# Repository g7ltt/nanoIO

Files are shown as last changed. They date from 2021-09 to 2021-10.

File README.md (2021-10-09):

# nanoIO
nanoIO CW/RTTY keyer for Arduino Nano

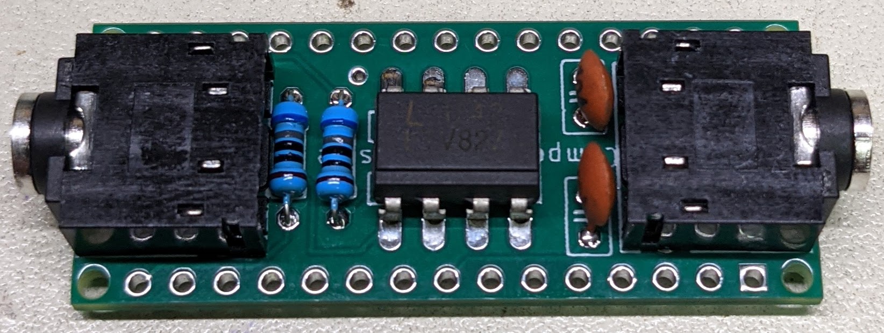
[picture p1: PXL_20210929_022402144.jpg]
finished board


My take on W1HKJ's nanoIO CW/RTTY keyer for FLDigi.

https://oshpark.com/shared_projects/0wyCgFsd

Mount the board component side down on the bottom of the Arduino Nano.

**_From the nanoIO website_**
NanoIO Version 1.3.1 
Authors: David Freese, W1HKJ & Ervin Hegedüs, HA2OS

An FSK / CW interface based on the Arduino nano. Sketch includes an FSK modulator, a CW computer interface, and a CW iambic-A/B keyer.

**FSK Specifications** 
* 5 bit Baudot
* Baud rates 45.45, 50, 75 and 100

**CW Specifications**
* 5 to 100 WPM
* dash/dot ratio adjustable 2.5 to 3.5
* in-line increment decrement WPM using ^ and | characters
* incremental size user adjustable
* PTT signal generated by Arduino

**Both**
* An internal buffer of 200 characters is available for buffered transmit.

**Hardware requirement**
* Arduino nano or compatible
* LTV-827 dual opto-isolator
* 2 620 ohm ¼ watt resistor (should work with 500 < R < 820 ohm)
* 2 0.1uF capacitor
* Suitable connectors to interface to transceiver

More information here http://www.w1hkj.com/files/nanoIO/

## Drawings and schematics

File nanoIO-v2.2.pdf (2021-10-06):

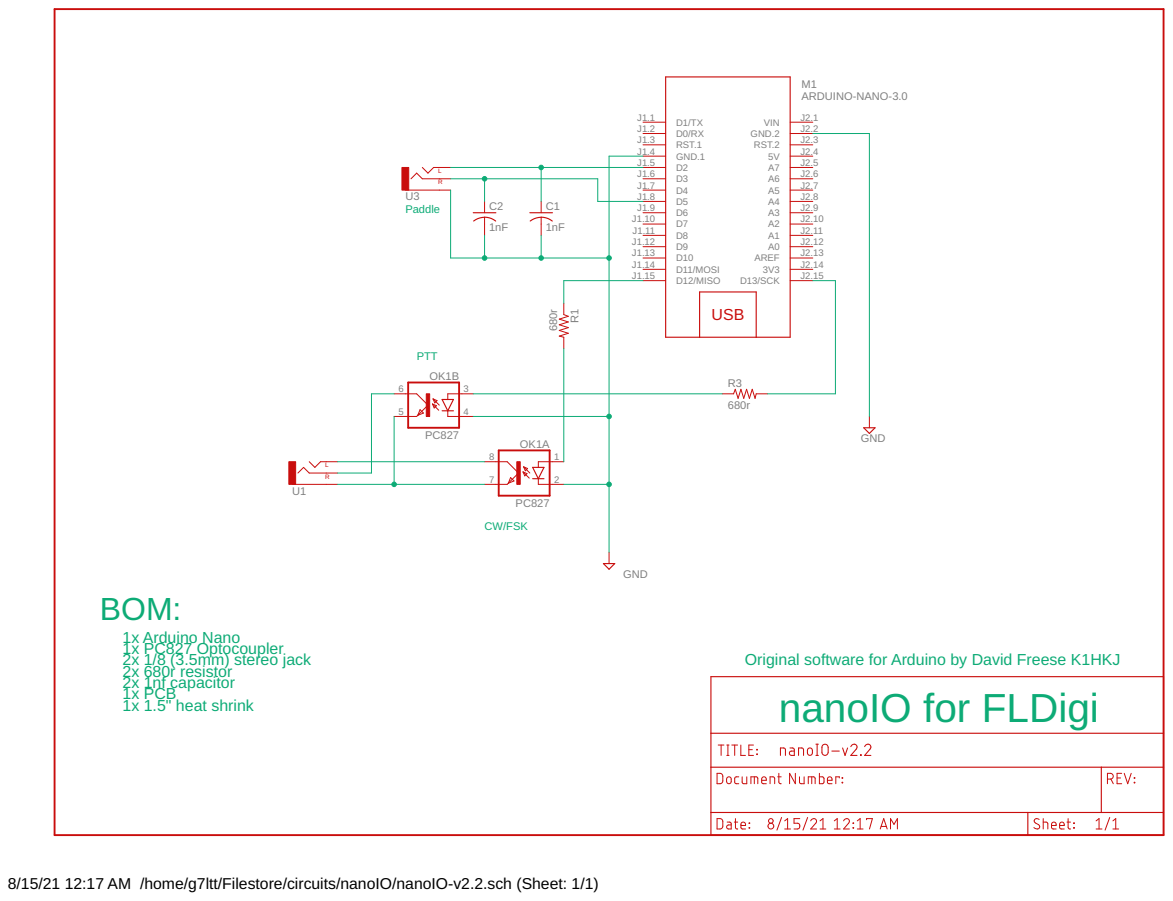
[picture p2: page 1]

Original software for Arduino by David Freese K1HKJ
nanoIO for FLDigi

8/15/21 12:17 AM /home/g7ltt/Filestore/circuits/nanoIO/nanoIO-v2.2.sch (Sheet: 1/1)

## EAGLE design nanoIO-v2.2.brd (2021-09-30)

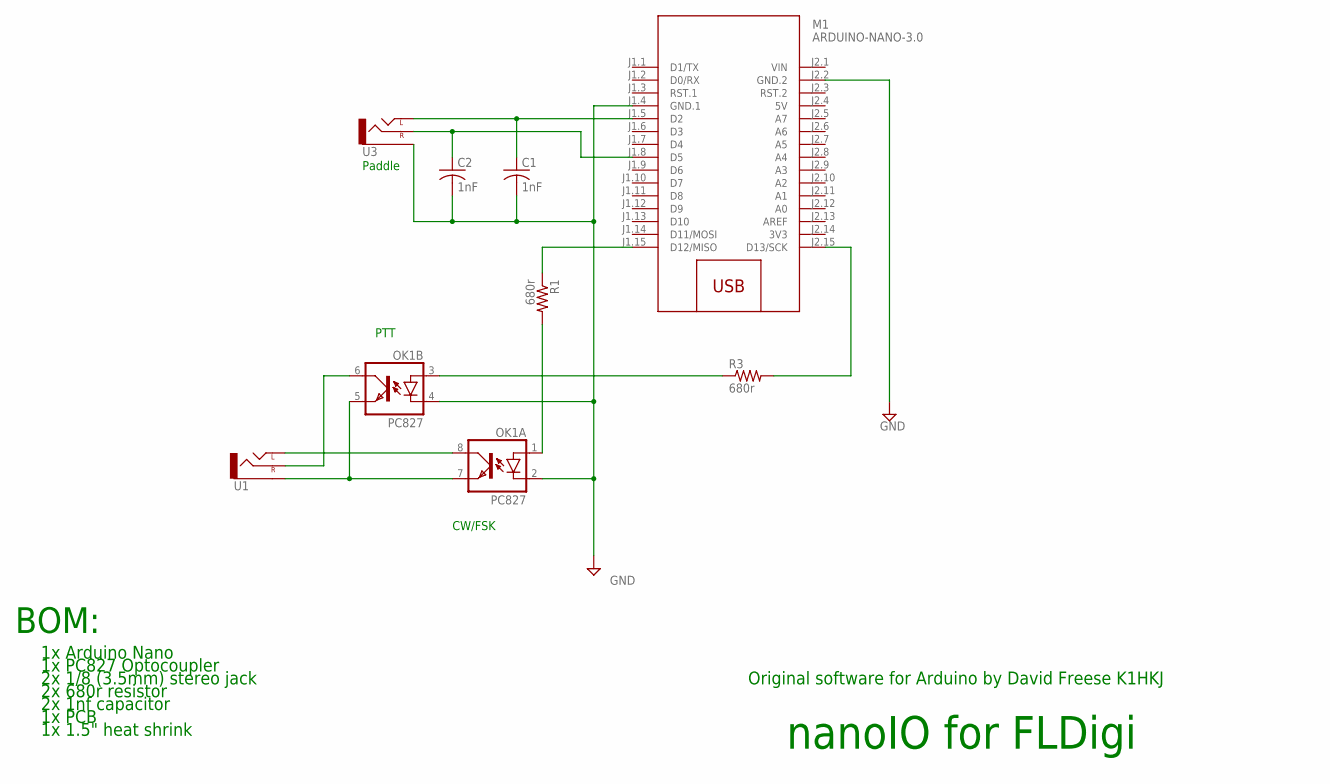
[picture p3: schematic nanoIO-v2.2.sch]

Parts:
C1, C2: 1nF; C025-025X050
M1: ARDUINO-NANO-3.0
OK1: PC827; DIL08
R1, R3: 680r; 0204/7
U1, U3: AUDIO-JACKPTH; AUDIO-JACK

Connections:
3V3: M1.J2.14 (3V3)
5V: M1.J2.4 (5V)
GND: C1.2, C2.2, M1.J1.4 (GND.1), M1.J2.2 (GND.2), OK1.2 (C), OK1.4 (C), U3.SLEEVE
unnamed: C1.1, M1.J1.5 (D2), U3.TIP (LEFT)
unnamed: OK1.1 (A), R1.2
unnamed: C2.1, M1.J1.8 (D5), U3.RING (RIGHT)
unnamed: M1.J2.15 (D13/SCK), R3.2
unnamed: M1.J1.15 (D12/MISO), R1.1
unnamed: OK1.5 (EMIT), OK1.7 (EMIT), U1.SLEEVE
unnamed: OK1.8 (COL), U1.TIP (LEFT)
unnamed: OK1.3 (A), R3.1
unnamed: OK1.6 (COL), U1.RING (RIGHT)
VIN: M1.J2.1 (VIN)

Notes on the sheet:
nanoIO for FLDigi
CW/FSK
Paddle
PTT
Original software for Arduino by David Freese K1HKJ
BOM:
1x Arduino Nano
1x PC827 Optocoupler
2x 1/8 (3.5mm) stereo jack
2x 680r resistor
2x 1nf capacitor
1x PCB
1x 1.5" heat shrink

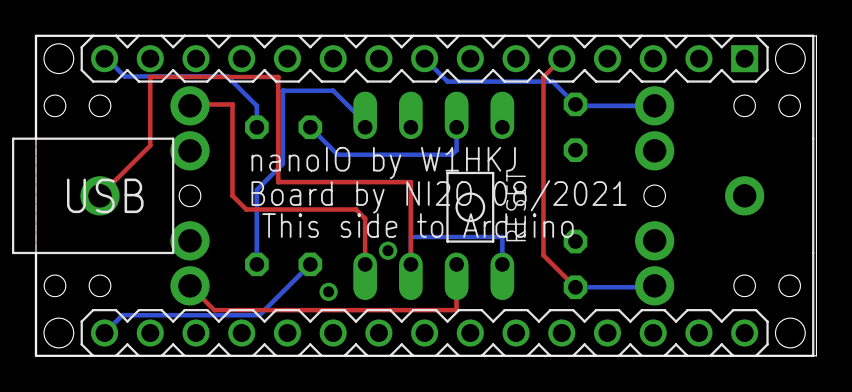
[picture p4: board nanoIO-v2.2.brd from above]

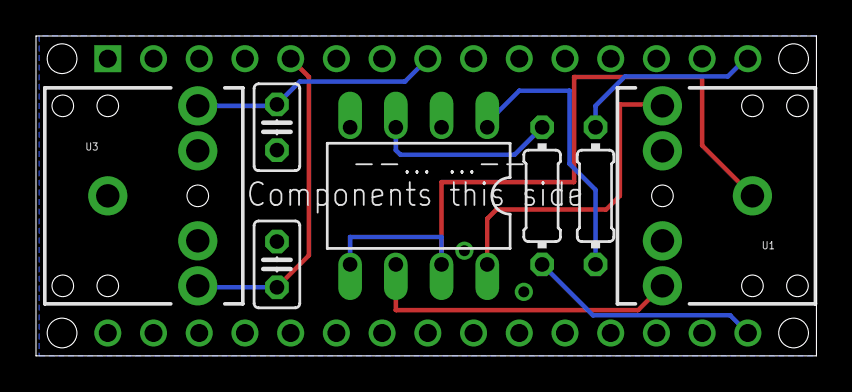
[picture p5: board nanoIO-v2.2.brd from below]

Board: 2 copper layers, 43.4 x 17.8 mm, 8 parts (7 on the bottom side), 10 nets.

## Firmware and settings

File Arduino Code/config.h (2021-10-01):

/***********************************************************************

  nanoIO

  CW / FSK interface sketch for use either stand alone or with fldigi.

  It is designed to fit within the RAM and I/O constraints of an Arduino 
  Nano circuit board.  It generates either CW 5 to 100 WPM Morse code, 
  or FSK Baudot hardline signals of 45.45, 50 or 75 Baud.

  Copyright (C) 2018 David Freese W1HKJ
  Derived from tinyFSK by Andrew T. Flowers K0SM

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
  Revisions:

  //1.0.0:  Initial release
  //1.0.1:  MORTTY Version 3 board support
  //1.1.0:  added support for WPM potentiometer; wiper on A0
  //1.3.0:  added additional FSK echo of control strings
  //1.3.1:  enabled keyline inputs
  //1.4.0:  MORTTY Version 4 board support
  //1.4.1:  Modified usec corr usage
  //1.4.1-NI2O Added NI2O board

***********************************************************************/
#ifndef _CONFIG_H_
#define _CONFIG_H_

#define VERSION "1.4.1"

// Configure for target h/w by removing the comment on the appropriate line
// ONLY one of the following:

//#define MORTTY_V2
//#define MORTTY_V3
//#define MORTTY_V4
//#define HA2OS
//#define W1HKJ
//#define N1MM
#define NI2O

// Configure for target h/w by removing the comment if your Morrty has a 
// speed pot:

//#define WITH_SPEED_POT

//----------------------------------------------------------------------
// values which may need to be changed depending on specific hardware
//----------------------------------------------------------------------

//----------------------------------------------------------------------
//Arduino pins for FSK, CW and PTT to control transmitter
// uncomment the desired h/w configuration
// comment the others

#ifdef MORTTY_V2
//----------------------------------------------------------------------
// Configuration for MORTTY Version 2 circuit board
//----------------------------------------------------------------------
#  define FSK_PIN 11
#  define CW_PIN  11
#  define PTT_PIN 13
#  define ST_Pin 4      // Sidetone Output Pin on Pin 4
// paddle input pins compatible with MORTTY board
#  define LP_in 2       // Left Paddle Input on Pin 2
#  define RP_in 5       // Right Paddle Input on Pin 5
#  define DEFAULT_MODE CW_MODE
#endif

#ifdef MORTTY_V3
//----------------------------------------------------------------------
// Configuration for MORTTY Version 3 circuit board
//----------------------------------------------------------------------
#  define FSK_PIN 11
#  define CW_PIN  12
#  define PTT_PIN 13
#  define ST_Pin 4      // Sidetone Output Pin on Pin 4
// paddle input pins compatible with MORTTY board
#  define RP_in 2       // Right Paddle Input on Pin 2
#  define LP_in 5       // Left Paddle Input on Pin 5
#  define DEFAULT_MODE CW_MODE
#  define WPM_POT 0
#endif

#ifdef MORTTY_V4
//----------------------------------------------------------------------
// Configuration for MORTTY Version 4 circuit board
//----------------------------------------------------------------------
#  define FSK_PIN 12
#  define CW_PIN  11
#  define PTT_PIN 13
#  define ST_Pin 4      // Sidetone Output Pin on Pin 4
// paddle input pins compatible with MORTTY board
#  define RP_in 2       // Right Paddle Input on Pin 2
#  define LP_in 5       // Left Paddle Input on Pin 5
#  define DEFAULT_MODE CW_MODE
#  define WPM_POT 0
#endif

#ifdef HA2OS
//----------------------------------------------------------------------
// Configuration for HA2OS quad opto-isolator circuit board design
//----------------------------------------------------------------------
#    define FSK_PIN 12
#    define CW_PIN  10
#    define PTT_PIN 11
#    define ST_Pin 4      // Sidetone Output Pin on Pin 4
//   paddle input pins
#    define LP_in 5       // Left Paddle Input on Pin 2
#    define RP_in 2       // Right Paddle Input on Pin 5
#    define DEFAULT_MODE CW_MODE
#endif

#ifdef W1HKJ
//----------------------------------------------------------------------
// Configuration for W1HKJ quad opto-isolator circuit board design
//----------------------------------------------------------------------
#    define FSK_PIN 12
#    define CW_PIN  11
#    define PTT_PIN 10
#    define ST_Pin 4      // Sidetone Output Pin on Pin 4
//   paddle input pins
#    define LP_in 2       // Left Paddle Input on Pin 2
#    define RP_in 5       // Right Paddle Input on Pin 5
#    define DEFAULT_MODE CW_MODE
#endif

#ifdef NI2O
//----------------------------------------------------------------------
// Configuration for NI2O dual opto-isolator circuit board design
//----------------------------------------------------------------------
#    define FSK_PIN 12
#    define CW_PIN  12
#    define PTT_PIN 13
#    define ST_Pin 4      // Sidetone Output Pin on Pin 4
//   paddle input pins
#    define LP_in 2       // Left Paddle Input on Pin 2
#    define RP_in 5       // Right Paddle Input on Pin 5
#    define DEFAULT_MODE CW_MODE
#endif

#endif // __CONFIG_H_

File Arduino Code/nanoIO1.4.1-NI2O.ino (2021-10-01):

/***********************************************************************

  nanoIO

  CW / FSK interface sketch for use either stand alone or with fldigi.

  It is designed to fit within the RAM and I/O constraints of an Arduino 
  Nano circuit board.  It generates either CW 5 to 100 WPM Morse code, 
  or FSK Baudot hardline signals of 45.45, 50 or 75 Baud.

  Copyright (C) 2018 David Freese W1HKJ
  Derived from tinyFSK by Andrew T. Flowers K0SM

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
  Revisions:

 //1.0.0:  Initial release
 //1.0.1:  MORTTY Version 3 board support
 //1.1.0:  added support for WPM potentiometer; wiper on A0
 //1.3.0:  added additional FSK echo of control strings
 //1.3.1:  enabled keyline inputs
 //1.4.0:  MORTTY Version 4 board support
 //1.4.1:  Modified usec corr usage
 //1.4.1-NI2O : Added NI2O board


***********************************************************************/

#include "TimerOne.h"
#include "Morse.h"
#include "Keyer.h"

#include "EEPROM.h"
#include "constants.h"
#include "ascii_map.h"

#include "config.h"

/******************************************************
     Variable declarations
*******************************************************/

/*******************************************************
  This section defines static runtime variables that affect
  RTTY transmission.  They are NOT directly changeable by user
  commands because they can get ops into trouble.  They are
  here for the tinkerer/experimenter in case you want access
  to them at runtime.
********************************************************/

long serialSpeed = 9600; //This is the speed for the serial
//(more likely USB) connection, 8-N-1

// Not user selectable, but USOS behavior can be changed here.
// We set this to TX extra shifts to be compatible with silly
// MMTTY default reciever
int usos = USOS_MMTTY_HACK;

int stopBits =  STOP_BITS_1R5;  // TX 1.5 stop bits

/***************************************
  Dynamic runtime variables these are minipulated with
  user commands or during normal TX operation.
*****************************************/
float baudrate = 45.45;  //default--can be changed by user command

int pttLeadMillis = 150; //time before first start bit
int pttTailMillis = 25;  //time after last stop bit


// Polarity--changed with user commands and stored in EEPROM
boolean mark = LOW;     //High indicates +V on the FSK/CW pin
boolean space = HIGH;   //Low indicates 0V on the FSK/CW pin

// Buffer management variables to handle TX text input
byte sendBufferArray[SEND_BUFFER_SIZE];  // size of TX buffer
byte sendBufferBytes = 0;    // number of bytes unsent in TX buffer
byte lastAsciiByteSent = 0;  // needed to echo back sent characters to terminal
boolean endWhenBufferEmpty = true;  //flag to kill TX when buffer empty (']')


byte currentShiftState = SHIFT_UNKNOWN;  //Keeps track of Letter/Figs state to determine
//if we need to send shift chars

boolean ptt = false; // Keeps track of PTT state (true = Transmitter is on)

volatile boolean isrFlag = false;   //set by timer interrupt.  Set high every 1/2 bit
//to indicate when we should exectute the bit-banging
//routine.  This is handled in the main loop function.

boolean configurationMode = false;  //flag indicates if we are in the menu system or
//in normal operation.

char mode = DEFAULT_MODE;
//----------------------------------------------------------------------
// CW variables

CWSTRUC CWstruc {
  18,      // int   cw_wpm;
  300,     // int   weight;
  2,       // int   incr;
  18,      // int   key_wpm;
  0,       // int   corr_usec
  IAMBICA, // int   keyer_mode;
  1,       // int   ptt_enable;
  10,      // int   pot min value;
  20       // int   pot range value;
};

boolean pot_control = true;
int     spd_cmd = 18;
float   wt_cmd = 3.0;

int     value = 0;
boolean value_string = false;
boolean pot_string = false;
boolean ptt_string = false;
boolean incr_char = false;

Morse morse(CWstruc.cw_wpm, CWstruc.weight/100.0);
Keyer keyer(CWstruc.key_wpm, CWstruc.weight/100.0);

//----------------------------------------------------------------------

/*********************************************************************
  Main execution
***********************************************************************/

/**
  Exectutes *once* at program start (when power applied or
  reset button pressed.  Note that many Arudino devices have a
  "software reset" option that will reset the processor when
  the serial port is opened.
  It opens the port, configures the output pins, and loads
  configuration from EEPROM.
*/

void setup()
{
// configure pins for output
  pinMode(FSK_PIN, OUTPUT);
  pinMode(PTT_PIN, OUTPUT);
  pinMode(CW_PIN, OUTPUT);

  eeLoad();

  morse.wpm(CWstruc.cw_wpm);
  morse.weight(CWstruc.weight/100.0);
  keyer.wpm(CWstruc.key_wpm);
  keyer.set_mode(CWstruc.keyer_mode);

  Serial.begin(serialSpeed);

// start the half-bit timer.
  initTimer();

//  resetSendBuffer();
  sendBufferBytes = 0;

//  morse.send('E', CW_PIN);

// Tell N1MM we are in "RX" mode.
  Serial.write("\ncmd:\n");

  morse.send('T', CW_PIN);
}

/**
  Main loop.  This loop does two things:
  (1) Process any input from the serial connection one byte at a time.

  (2) If the half-bit timer interrupt fired we need to execute the bit-banging
  routine to keep clocking out RTTY.
*/

void do_serial()
{
// Read up to SEND_BUFFER_SIZE characters from the USB serial port

  while ((Serial.available() > 0) && (sendBufferBytes < SEND_BUFFER_SIZE)) {

// get incoming byte:
    byte b = Serial.read();

// Process configuration string if we are in configuration mode
    if (configurationMode) {
      echo(b);
      handleConfigurationCommand(b);
    }
    else  switch (b) {
// test for configuration mode character
      case COMMAND_ESCAPE :
        configurationMode = true;
        echo(b);
        break;
// check for TX abort character.  This immediately kills the
// transmitter and dumps anything remaining in the buffer.
      case TX_ABORT : 
        echo(b);
        setPTT(false);
        resetSendBuffer();
        endWhenBufferEmpty = true;
        break;
      case TX_ON : 
        echo(b);
        endWhenBufferEmpty = false;
        setPTT(true);
        break;
      case TX_END : 
        echo(b);
        endWhenBufferEmpty = true;
        break;
      default :
// add character (b) to send buffer
        if (b == 0) break;
        if (mode == FSK_MODE)
          addToSendBuffer(b);
        else {
          if (b < ' ') {
            addToSendBuffer(' ');
          } else {
            addToSendBuffer(b);
          }
        }
      }
  }  // end while (Serial.available...)

// If the ISR fired we need may need to bit-bang something out the FSK port
  if (mode == FSK_MODE) {
    if (isrFlag) {
      processHalfBit();
      isrFlag = false;
    } else
      isrFlag = false;
  }
  else { // mode is CW_MODE
    if (sendBufferBytes > 0) {
      send_next_CW_char();
    } else if (endWhenBufferEmpty) {
      setPTT(false);
      endWhenBufferEmpty = false;
    }
  }
}

void send_wpm()
{
  Serial.write("\nwpm "); Serial.println(CWstruc.key_wpm);
}


void send_ptt_state()
{
  Serial.write("ptt ");
  if (CWstruc.ptt_enable) Serial.write(" enabled\n");
  else Serial.write(" disabled");
}
  
// Read A0, wiper arm of speed pot, 0 ... 5 v
// convert to wpm MIN ... MAX

void read_pot_wpm()  
{
#ifdef WITH_SPEED_POT
  int pot_wpm = CWstruc.min_pot_wpm + CWstruc.rng_pot_wpm * analogRead(WPM_POT) / 1023;

  if ((pot_control == 1) && (pot_wpm != CWstruc.cw_wpm)) {
    CWstruc.key_wpm = pot_wpm;
    keyer.wpm(CWstruc.key_wpm);
  }
#endif
}

void loop()
{
  if (mode == CW_MODE) {
    read_pot_wpm();
    if (!keyer.do_paddles()) 
      do_serial();
  } else
    do_serial(); 
}

// Handle configuration change commands by changing variables
// and writing new values to EEPROM.
//
// Configuration change commands are preceded by the ~ character
//
// ~A, ~a - IambicA keying
// ~B, ~b - IambicB keying
// ~K, ~k - Straight Key
// ~C, ~c - change to CW output
// ~E, ~e - timing error corr in usec
// ~F, ~f - change to FSK output
// ~P1    - CW WPM Pot control ON
// ~P0    - CW WPM Pot control OFF
// ~P?    - CW WPM reading
// ~X0    - disable PTT
// ~X1    - enable PTT
// ~X?    - PTT state
// ~T, ~t - enable CW tune position (] terminates)
// ~Snnns - change CW WPM to nnn
// ~Unnnu - change CW keyer WPM to nnn
// ~Dnnnd - change CW dash/dot ratio to nnn/100
// ~In    - change CW incr/decr value (1...9)
// ~0     - Set FSK mark = HIGH
// ~1     - Set FSK mark = LOW
// ~4     - Set FSK baud to 45.45
// ~5     - Set FSK baud to 50.0
// ~7     - Set FSK baud to 75.0
// ~9     - Set FSK baud to 100.0
// ~?     - Report current configuration
// ~W     - Save config to EEPROM
// ~~     - Show command set

void handleConfigurationCommand(byte b)
{
  if (value_string && b >= '0' && b <= '9') {
    value = value * 10 + b - '0';
    return;
  }
  if (pot_string) {
    if (b == '1') pot_control = 1;
    else if (b == '0') pot_control = 0;
    else if (b == '?') send_wpm();
    pot_string = false;
    configurationMode = false;
    return;
  }
  if (ptt_string) {
    if (b == '1') CWstruc.ptt_enable = 1;
    else if (b == '0') CWstruc.ptt_enable = 0;
    else if (b == '?') send_ptt_state(); 
    ptt_string = false;
    configurationMode = false;
    return;
  }
  if (incr_char) {
    int val = b - '0';
    if (val > 0 && val < 10) CWstruc.incr = val;
    incr_char = false;
  }

  switch (b) {
    case 'A' : case 'a' :
        CWstruc.keyer_mode = IAMBICA;
        keyer.set_mode(IAMBICA);
        configurationMode = false;
        break;
    case 'B' : case 'b' :
        CWstruc.keyer_mode = IAMBICB;
        keyer.set_mode(IAMBICB);
        configurationMode = false;
        break;
    case 'K' : case 'k':
        CWstruc.keyer_mode = STRAIGHT;
        keyer.set_mode(STRAIGHT);
        configurationMode = false;
        break;
    case 'C' : case 'c' :
        mode = CW_MODE;
        configurationMode = false;
        break;
    case 'F' : case 'f' :
        mode = FSK_MODE;
        configurationMode = false;
        break;
    case 'P' : case 'p' :
        pot_string = true;
        break;
    case 'X': case 'x' :
        ptt_string = true;
        break;
    case 'T' : case 't' :
        enable_tune();
        configurationMode = false;
        break;
    case COMMAND_POLARITY_MARK_HIGH :
        mark = HIGH;
        space = LOW;
        EEPROM.write(EE_POLARITY_ADDR, b);
        configurationMode = false;
        break;
    case COMMAND_POLARITY_MARK_LOW :
        mark = LOW;
        space = HIGH;
        EEPROM.write(EE_POLARITY_ADDR, b);
        configurationMode = false;
        break;
    case COMMAND_45BAUD :
        baudrate = 45.45;
        initTimer();
        EEPROM.write(EE_SPEED_ADDR, b);
        configurationMode = false;
        break;
    case COMMAND_50BAUD :
        baudrate = 50.0;
        initTimer();
        EEPROM.write(EE_SPEED_ADDR, b);
        configurationMode = false;
        break;
    case COMMAND_75BAUD :
        baudrate = 75.0;
        initTimer();
        EEPROM.write(EE_SPEED_ADDR, b);
        configurationMode = false;
        break;
    case COMMAND_100BAUD :
        baudrate = 100.0;
        initTimer();
        EEPROM.write(EE_SPEED_ADDR, b);
        configurationMode = false;
        break;
    case 'D' : // start dash/dot ratio
        value_string = true;
        value = 0;
        return;
    case 'd' : // end dash/dot ratio
        value_string = false;
        if (value >= 250 && value <= 350) {
          CWstruc.weight = value;
          morse.weight(CWstruc.weight/100.0);
        }
        configurationMode = false;
        break;
    case 'E' : // start timing error usec
        value_string = true;
        value = 0;
        return;
    case 'e' : // end dash/dot ratio
        value_string = false;
        CWstruc.corr_usec = value;
        configurationMode = false;
        break;
    case 'I' : case 'i' : // incr/dec value
        incr_char = true;
        return;
    case 'S' : // start Speed (wpm)
        value_string = true;
        value = 0;
        return;
    case 's' : // end speed
        value_string = false;
        if (value >= MIN_CW_WPM && value <= MAX_CW_WPM) {
          CWstruc.cw_wpm = value;
          morse.wpm(CWstruc.cw_wpm);
        }
        configurationMode = false;
        break;
    case 'U' : // start key wpm (user)
        value_string = true;
        value = 0;
        return;
    case 'u' : // end speed
        value_string = false;
        if (value >= MIN_CW_WPM && value <= MAX_CW_WPM) {
          CWstruc.key_wpm = value;
          keyer.wpm(CWstruc.key_wpm);
        }
        configurationMode = false;
        break;

    case 'M' : // start pot min wpm 
        value_string = true;
        value = 0;
        return;
    case 'm' : // end pot min wpm
        value_string = false;
        CWstruc.min_pot_wpm = value;
        configurationMode = false;
        break;

    case 'N' : // start pot range wpm 
        value_string = true;
        value = 0;
        return;
    case 'n' : // end pot min wpm
        value_string = false;
        CWstruc.rng_pot_wpm = value;
        configurationMode = false;
        break;

    case COMMAND_DUMP_CONFIG :
        displayConfiguration();
        configurationMode = false;
        break;
    case 'W' : case 'w' :
      eeSave();
      configurationMode = false;
      break;
    case COMMAND_ESCAPE :
      displayConfigurationPrompt();
      configurationMode = false;
      break;
    default :
      value_string = false;
      configurationMode = false;
      pot_string = false;
      ptt_string = false;
      Serial.write("\nCommand?\n");
  }
}

/**
  Loads speed and polarity from EEPROM
*/
void eeLoad()
{
  mode           = EEPROM.read(EE_MODE);
  if (mode != CW_MODE && mode != FSK_MODE) mode = CW_MODE;
  byte speedChar = EEPROM.read(EE_SPEED_ADDR);
  byte polarity  = EEPROM.read(EE_POLARITY_ADDR);

  if (polarity == COMMAND_POLARITY_MARK_LOW) {
    mark = LOW;
  } else {
    mark = HIGH;
  }
  space = !mark;

  switch (speedChar) {
    case COMMAND_50BAUD :
        baudrate = 50.0;
        break;
    case COMMAND_75BAUD :
        baudrate = 75.0;
        break;
    case COMMAND_100BAUD :
        baudrate = 100.0;
        break;
    default:
        baudrate = 45.45;
        break;
  }

  EEPROM.get(EE_CW_STRUC_ADDR, CWstruc);
  if (CWstruc.cw_wpm < MIN_CW_WPM) CWstruc.cw_wpm = 18;
  if (CWstruc.cw_wpm > MAX_CW_WPM) CWstruc.cw_wpm = 18;
  if (CWstruc.key_wpm < MIN_CW_WPM) CWstruc.key_wpm = 18;
  if (CWstruc.key_wpm > MAX_CW_WPM) CWstruc.key_wpm = 18;
  if (CWstruc.weight < 250) CWstruc.weight = 300;
  if (CWstruc.weight > 350) CWstruc.weight = 300;
  if (CWstruc.ptt_enable < 0 || CWstruc.ptt_enable > 1) CWstruc.ptt_enable = 1;
  if (CWstruc.min_pot_wpm < 5 || CWstruc.min_pot_wpm > 100) CWstruc.min_pot_wpm = 5;
  if (CWstruc.rng_pot_wpm < 10 || CWstruc.rng_pot_wpm > 30) CWstruc.rng_pot_wpm = 20;
  if (CWstruc.incr < 1) CWstruc.incr = 2;
  if (CWstruc.incr > 9) CWstruc.incr = 2;
//  eeSave();
}

void eeSave()
{
  EEPROM.write(EE_MODE, mode);
  if (baudrate == 45.45) EEPROM.write(EE_SPEED_ADDR, COMMAND_45BAUD);
  if (baudrate == 50.0)  EEPROM.write(EE_SPEED_ADDR, COMMAND_50BAUD);
  if (baudrate == 75.0)  EEPROM.write(EE_SPEED_ADDR, COMMAND_75BAUD);
  if (baudrate == 100.0) EEPROM.write(EE_SPEED_ADDR, COMMAND_100BAUD);
  if (mark == LOW) EEPROM.write(EE_POLARITY_ADDR, COMMAND_POLARITY_MARK_LOW);
  else             EEPROM.write(EE_POLARITY_ADDR, COMMAND_POLARITY_MARK_HIGH);

  EEPROM.put(EE_CW_STRUC_ADDR, CWstruc);
}

/**
  Init the timer to fire every *half* bit period.  This allows us
  to have 1.5 stop bits if we want.
*/
void initTimer()
{
  Timer1.stop();
  long bitPeriod = (long) ((1.0f / baudrate) * 1000000); //micros
  Timer1.initialize(bitPeriod / 2.0);
  Timer1.attachInterrupt(timerISR);
}

/**
  The ISR for the half-bit timer is just to set a flag.  We
  will process in the main loop.
*/
void timerISR()
{
  isrFlag = true;
}

/**
  Displays the configuration options on the console
*/
void displayConfigurationPrompt()
{
Serial.write("\
\nCmd ~...\
\nC,c   CW\
\nF,f   FSK\
\nT,t   Tune\
\nSvvvs comp wpm\
\nUvvvu key wpm\
\nDvvvd dash/dot");
 #ifdef WITH_SPEED_POT
Serial.write("\
\nP0    pot disabled\
\nP1    pot enabled\
\nP?    pot wpm\
\nMvvvm pot min\
\nNvvvn pot range");
 #endif
Serial.write("\
\nX0    ptt ON\
\nX1    ptt OFF\
\nX?    ptt state");
Serial.write("\
\nIn    incr\
\nA,a   IambicA\
\nB,b   IambicB\
\nK,k   Straight\
\n0     mark HIGH\
\n1     mark LOW\
\n4     45.45 baud\
\n5     50 baud\
\n7     75 baud\
\n9     100 baud\
\n?     Show config\
\nW     Write EEPROM\
\n~     Show cmds\n");
}

/**
  Prints the current configuration the console
*/
void displayConfiguration()
{
  Serial.write("\nnanoIO ver ");
  Serial.write(VERSION);
  Serial.write("\nMode ");
  if (mode == FSK_MODE)
    Serial.write("FSK");
  else
    Serial.write("CW");
  Serial.write("\nFSK");
  Serial.write("\n  Baud "); Serial.print(baudrate);
  Serial.write("\n  Mark ");
  if (mark == LOW) {
    Serial.write("LOW");
  } else {
    Serial.write("HIGH");
  }
  Serial.write("\nCW");
  Serial.write("\n      PC WPM "); Serial.print(CWstruc.cw_wpm);
  Serial.write("\n  Paddle WPM "); Serial.print(CWstruc.key_wpm);
  Serial.write("\n   corr usec "); Serial.print(CWstruc.corr_usec);
  Serial.write("\n    dash/dot "); Serial.print(CWstruc.weight/100.0);
  Serial.write("\n        incr "); Serial.print(CWstruc.incr);
  Serial.write("\n  Keyer mode ");
  if (keyer.get_mode() == STRAIGHT) Serial.write("Straight");
  else if (keyer.get_mode() == IAMBICA) Serial.write("IambicA");
  else Serial.write("IambicB");
#ifdef WITH_SPEED_POT
  Serial.write("\n   Speed Pot "); Serial.print(pot_control ? "ON" : "OFF");
  Serial.write("\n     minimum "); Serial.print(CWstruc.min_pot_wpm);
  Serial.write("\n       range "); Serial.print(CWstruc.rng_pot_wpm);
#endif
  Serial.write("\nPTT "); Serial.write(CWstruc.ptt_enable ? "YES" : "NO");
  Serial.write("\n");
}

/******************************************************************
   handle CW characters in buffer
*/
void send_next_CW_char()
{
  if (sendBufferBytes > 0) {
    byte chr = sendBufferArray[0];
    for (int i = 0; i < sendBufferBytes - 1; i++) {
      sendBufferArray[i] = sendBufferArray[i + 1];
    }
    sendBufferBytes--;
    if (chr == '^') {
      CWstruc.cw_wpm += CWstruc.incr;
      if (CWstruc.cw_wpm > 100) CWstruc.cw_wpm = 100;
      morse.wpm(CWstruc.cw_wpm);
      return;
    }
    if (chr == '|') {
      CWstruc.cw_wpm -= CWstruc.incr;
      if (CWstruc.cw_wpm < 5) CWstruc.cw_wpm = 5;
      morse.wpm(CWstruc.cw_wpm);
      return;
    }
    morse.send(chr, CW_PIN);
    echo(chr);
  }
}

/******************************************************************
  This called every half-bit period to figure out what to bit-bang
  out the FSK pin.  It is basically an incremental counter that
  counts half bit periods and toggles the bits of the baudot character
  as needed.  It bangs out the start bit, five symbol bits, and the
  stop bit, which is 1.5 bits long (hence the need to have a timer
  counting half bits).
  The 5 bit RTTY character frame looks like this:

        ||Start | LSB |  X  |  X  |  X  | MSB | Stop    ||
  bitPos:   -1     0     1     2     3     4      5
******************************************************************/
int sendingChar = LTRS_SHIFT; // default--this is the "diddle character"
int stopBitCounter = 0; // counts half-bits for stop bit
int bitPos = START_BIT_POS;        // -1 = Start bit
bool midBit = false;    // used as like an ignore flag--we usually don't
// toggle state in the middle of a bit.  The exception
// is the stop bit, which is often 1.5 bits long.
void processHalfBit() {

  if (!ptt)  //not transmitting, so just return--there's nothing to send.
    return;

  if (midBit) {
    midBit = false; // reset the flag.  Next time we need to send the next bit.
    return;
  }

  // it's time to bang out the next bit.  We check for the special cases
  // first.  If it's a start bit we always sent SPACE and if its a STOP bit
  // we always send MARK.
  if (bitPos == START_BIT_POS) {  // we have to send a start bit

// If it is time to send a start bit, we grab the next character to send so
// that it is ready the next time through the loop.  The next character
// might be the TX_END_FLAG, in which case we need to turn off the transmitter.
    sendingChar = getNextSendChar();

    if (ptt) {
      if (sendingChar == TX_END_FLAG) { //end of data to send
        setPTT(false);
        return;
      } else {
        digitalWrite(FSK_PIN, space);  //start bit is always space
        bitPos++;
        midBit = true;
      }
    }
  }
  else if (bitPos == STOP_BIT_POS) { // we have to send a stop bit
    if (stopBitCounter == 0) {
      digitalWrite(FSK_PIN, mark);
      stopBitCounter = stopBits;  //this determines # of half-bit periods we stay in stop bit
    } else { // already in stop bit, just decrement
// stopBitCounter counts half-bit periods.  2 ==> one stop bit
//                                          3 ==> 1.5 stop bits
//                                          4 ==> two stop bits
      stopBitCounter--;
      if (stopBitCounter == 0) { // end of stop bit period
        bitPos = START_BIT_POS;  // move on to start bit of next char
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

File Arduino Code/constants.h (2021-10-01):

/***********************************************************************

  nanoIO

  CW / FSK interface sketch for use either stand alone or with fldigi.

  It is designed to fit within the RAM and I/O constraints of an Arduino 
  Nano circuit board.  It generates either CW 5 to 100 WPM Morse code, 
  or FSK Baudot hardline signals of 45.45, 50 or 75 Baud.

  Copyright (C) 2018 David Freese W1HKJ
  Derived from tinyFSK by Andrew T. Flowers K0SM

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
  Revisions:

  //1.0.0:  Initial release
  //1.0.1:  MORTTY Version 3 board support
  //1.1.0:  added support for WPM potentiometer; wiper on A0

***********************************************************************/

#ifndef _CONSTANTS_H_
#define _CONSTANTS_H_

//BUFFER SETTINGS
// Allow up to 300 chars in the buffer before overrunning (wrapping around).
// This can be increased on most boards with more RAM.
#define SEND_BUFFER_SIZE 300

#define MIN_CW_WPM 5
#define MAX_CW_WPM 100

#define MIN_POT_WPM 5
#define MAX_POT_WPM 35
#define WPM_POT 0
///---------------------------------------------------------------------

//EEPROM addresses to persist configuration
#define EE_MODE 0
#define EE_SPEED_ADDR 1
#define EE_POLARITY_ADDR 2
#define EE_CW_STRUC_ADDR 3

//Special Baudot symbols for shift
#define LTRS_SHIFT 0x1F  //baudot letter shift byte
#define FIGS_SHIFT 0x1B  //baudot figs shift byte

#define SHIFT_UNKNOWN 0  //Undefined shift--used at TX start to force shift state

//Special ASCII SYMBOLS (8 bit)
#define ASCII_NULL 0x00
#define ASCII_LF 0x0A
#define ASCII_CR 0x0D

#define TX_END_FLAG 0xFF      // Used in Baudot stream to indicate EOT

//References used in banging out the bits for 5-bit baudot. These
//are relative to the first data bit in the frame.
#define START_BIT_POS -1
#define STOP_BIT_POS 5

//Commands that control transmitter sequencing
#define TX_ON '['   // TX now => {TX} in N1MM
#define TX_END ']'  // Buffered switch to RX => {END} in N1MM
#define TX_ABORT '\\' // (Backslash) Immediate switch to RX and clear buffer => {ESC} in N1MM

//Configuration commands.  These are also the values saved in the EEPROM.
#define COMMAND_ESCAPE '~'
#define COMMAND_POLARITY_MARK_HIGH '0'
#define COMMAND_POLARITY_MARK_LOW  '1'
#define COMMAND_45BAUD '4'
#define COMMAND_50BAUD '5'
#define COMMAND_75BAUD '7'
#define COMMAND_100BAUD '9'
#define COMMAND_DUMP_CONFIG '?'

// Stop bit settings
#define STOP_BITS_1     1    // 1 stop bit
#define STOP_BITS_1R5   2    // 1.5 stop bits
#define STOP_BITS_2     3    // 2 stop bits

// TX USOS settings
#define USOS_OFF  1       //Assumes that RX will not reset to LTRS shift after space
//All shift symbols are explicit and spaces do not change
//shift state:
//  K0SM 599 05 NY NY
//     --> <LTR>K<FIG>0<LTR>SM <FIG>599 05 <LTR>NY NY

#define USOS_ON 2         //Space is an implicit LTRS shift character.  "Ham standard"
//demodulators operate in this mode.
//  K0SM 599 05 NY NY
//     --> <LTR>K<FIG>0<LTR>SM <FIG>599 <FIG>05 NY NY

#define USOS_MMTTY_HACK 3 //Essentially USOS OFF plus extra FIGS shifts for all words
//starting with numbers.  This is what MMTTY somewhat misleadingly
//calls "USOS transmission."  This settings makes many contest exchanges
//longer (and slightly more prone to bit errors) all to be
//compatible with MMTTY's non-USOS RX default
//  K0SM 599 05 NY NY
//     --> <LTR>K<FIG>0<LTR>SM <FIG>599 <FIG>05 <LTR>NY NY

#define CW_MODE 'C'
#define FSK_MODE 'F'

#endif // _CONSTANTS_H_

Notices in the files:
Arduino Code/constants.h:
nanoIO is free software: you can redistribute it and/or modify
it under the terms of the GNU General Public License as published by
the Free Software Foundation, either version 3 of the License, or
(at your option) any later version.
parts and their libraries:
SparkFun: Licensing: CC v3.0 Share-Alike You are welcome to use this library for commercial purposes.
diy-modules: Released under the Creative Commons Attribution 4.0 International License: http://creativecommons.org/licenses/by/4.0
